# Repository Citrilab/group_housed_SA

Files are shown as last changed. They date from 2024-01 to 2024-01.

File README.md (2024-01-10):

# group_housed_SA
This repository includes appendix files for the paper: 
"An automated group-housed oral fentanyl self-administration method in mice" 
published in Psychopharmacology. 
It contains information regarding the assembly and use of the HOMECAGE (Home-cage Observation and Measurement for Experimental Control and Analysis in a Group-housed Environment).

3 folders are included:
* Assembly files - how to build a cage hardware, technical details, and 3D print files. 
* protocols – protocols for fixed ratio and progressive ratio self-administration group housed experiments in an automated cage, meant to be run by ‘Bpod’ hardware and software (https://sanworks.github.io/Bpod_Wiki/)
* Bpod helper – A GUI that helps the user to manage a group housed experiment using Bpod. including a user manual for this GUI.

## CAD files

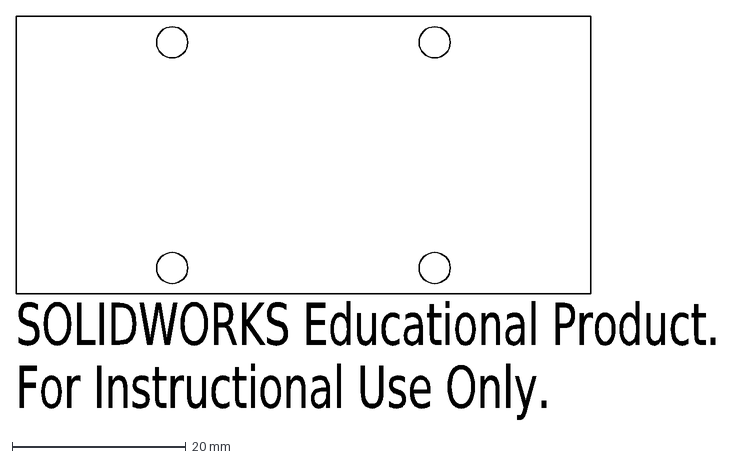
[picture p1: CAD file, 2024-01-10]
Assembly files/behavioral zone/Plexiglass top .DXF
SOLIDWORKS Educational Product.
For Instructional Use Only.

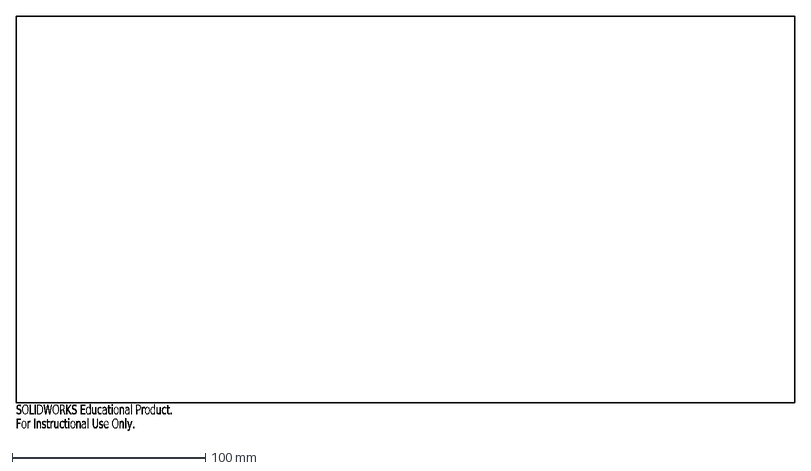
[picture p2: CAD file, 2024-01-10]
Assembly files/cage/Sides (2 parts).DXF
SOLIDWORKS Educational Product.
For Instructional Use Only.

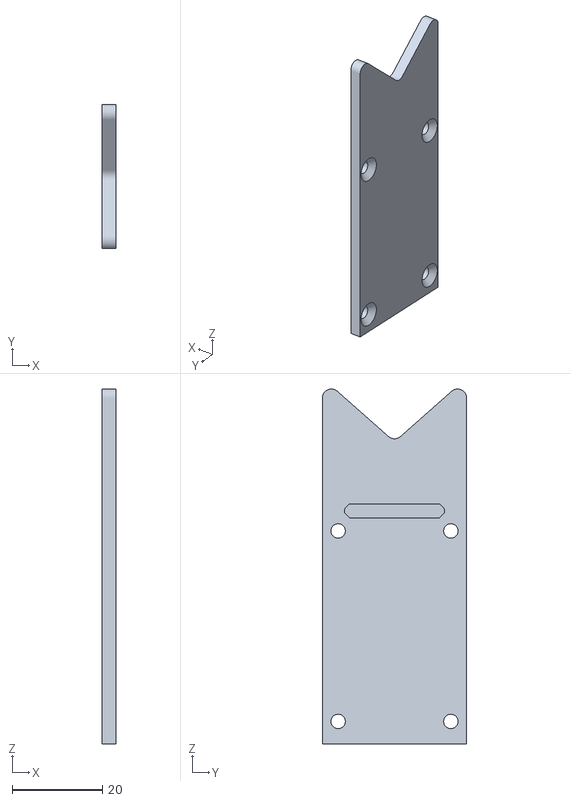
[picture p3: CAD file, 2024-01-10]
Assembly files/behavioral zone/side 1.STL
3.00 x 32.0 x 78.7

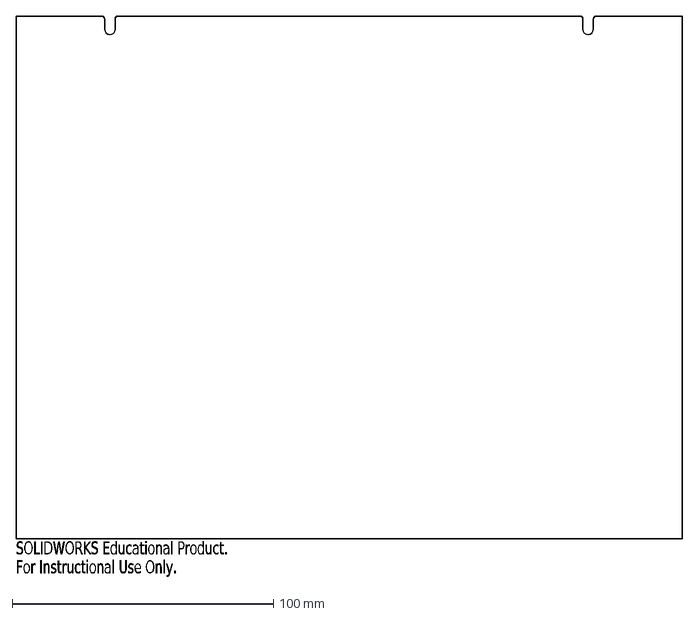
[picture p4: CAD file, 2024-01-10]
Assembly files/cage/Back.DXF
SOLIDWORKS Educational Product.
For Instructional Use Only.

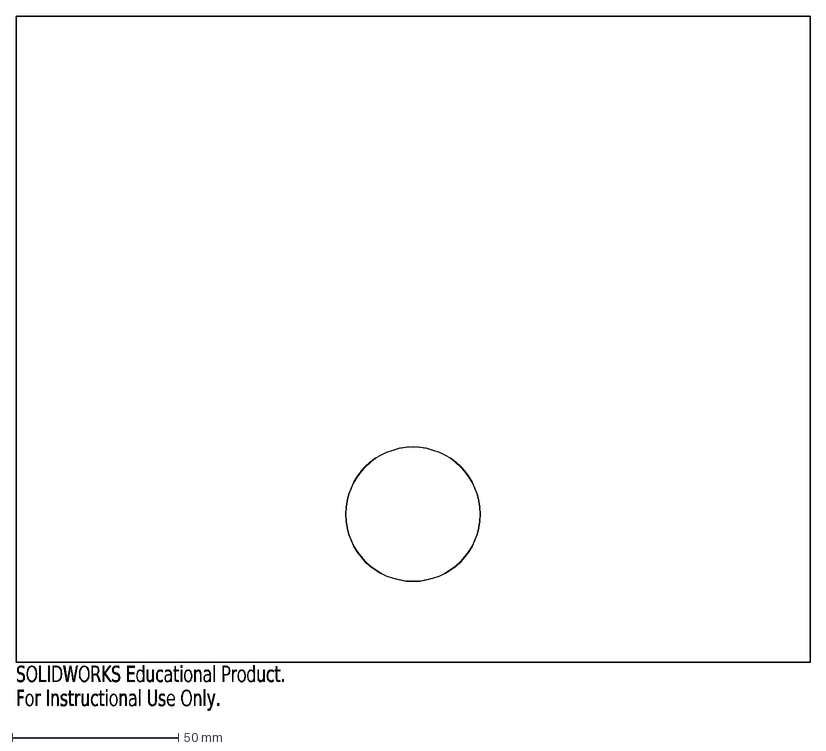
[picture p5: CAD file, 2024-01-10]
Assembly files/cage/Partition.DXF
SOLIDWORKS Educational Product.
For Instructional Use Only.

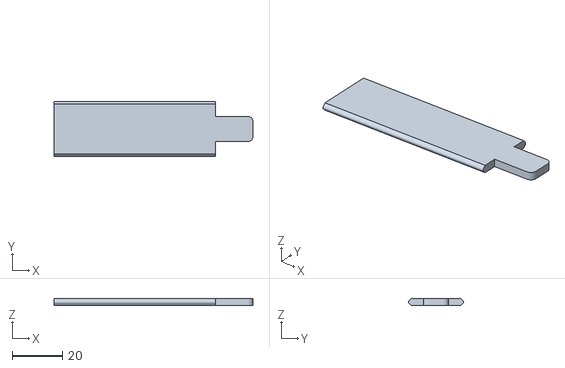
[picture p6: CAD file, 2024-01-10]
Assembly files/behavioral zone/floor.STL
79.3 x 21.9 x 2.70

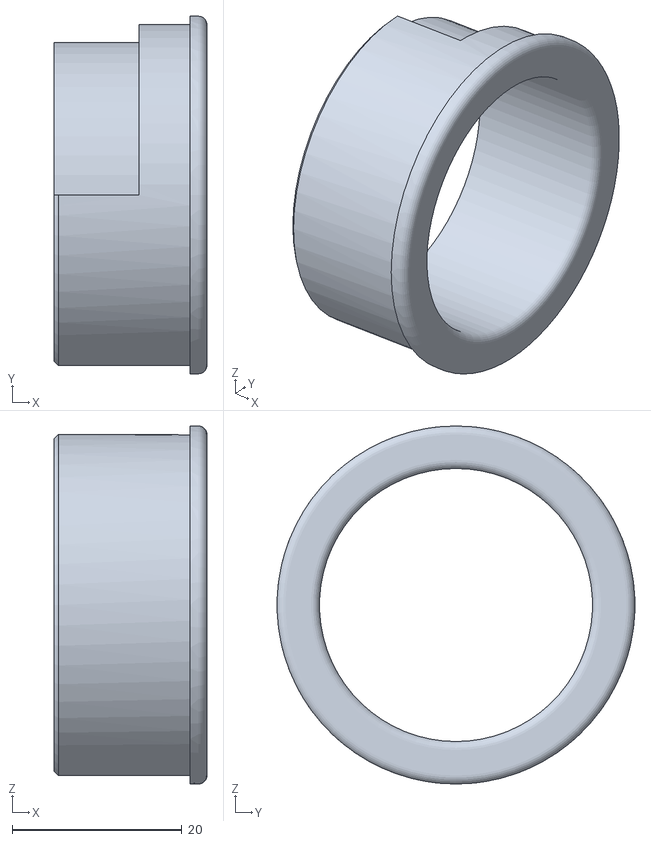
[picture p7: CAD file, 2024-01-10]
Assembly files/cage/Pipe holder.STL
18.0 x 42.1 x 42.1

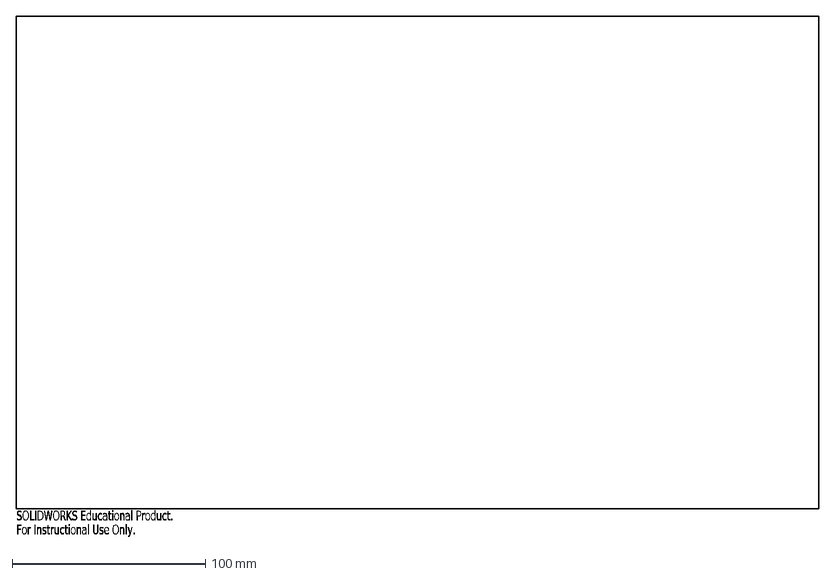
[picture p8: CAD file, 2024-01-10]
Assembly files/cage/Floor.DXF
SOLIDWORKS Educational Product.
For Instructional Use Only.

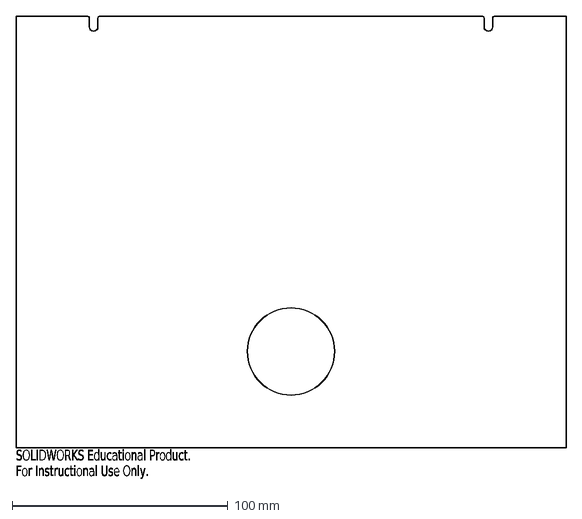
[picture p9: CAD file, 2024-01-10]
Assembly files/cage/Front.DXF
SOLIDWORKS Educational Product.
For Instructional Use Only.

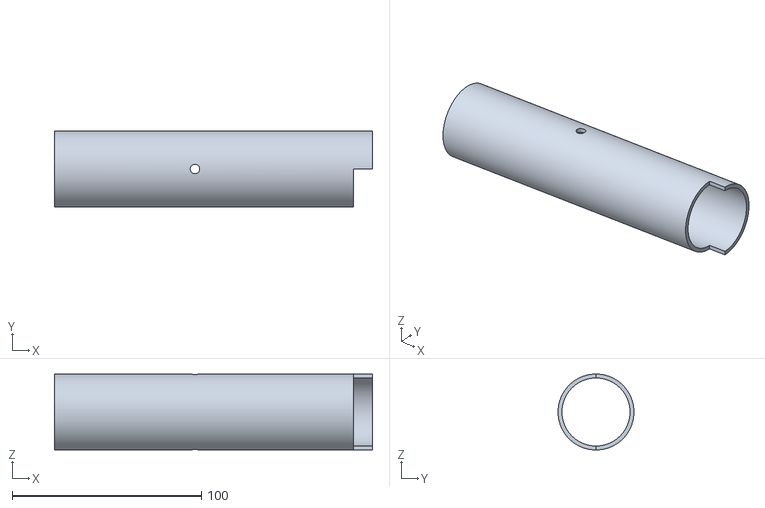
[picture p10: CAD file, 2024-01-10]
Assembly files/cage/Pipe for double port (Transparent).STL
168.0 x 40.1 x 40.1

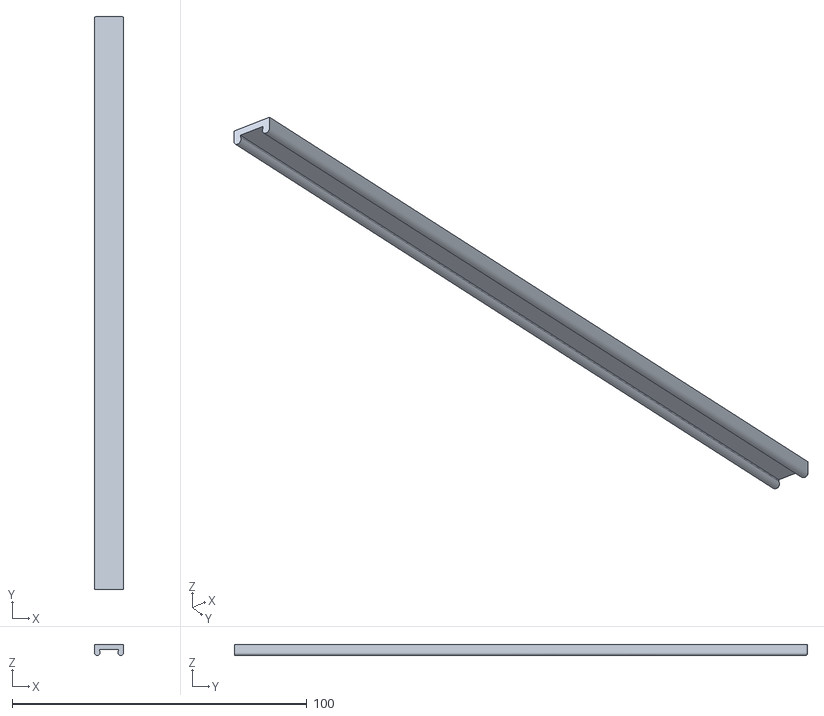
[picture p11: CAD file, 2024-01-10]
Assembly files/cage/Rails (2 parts).STL
10.0 x 194.3 x 3.70

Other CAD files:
Assembly files/behavioral zone/side 2.STL

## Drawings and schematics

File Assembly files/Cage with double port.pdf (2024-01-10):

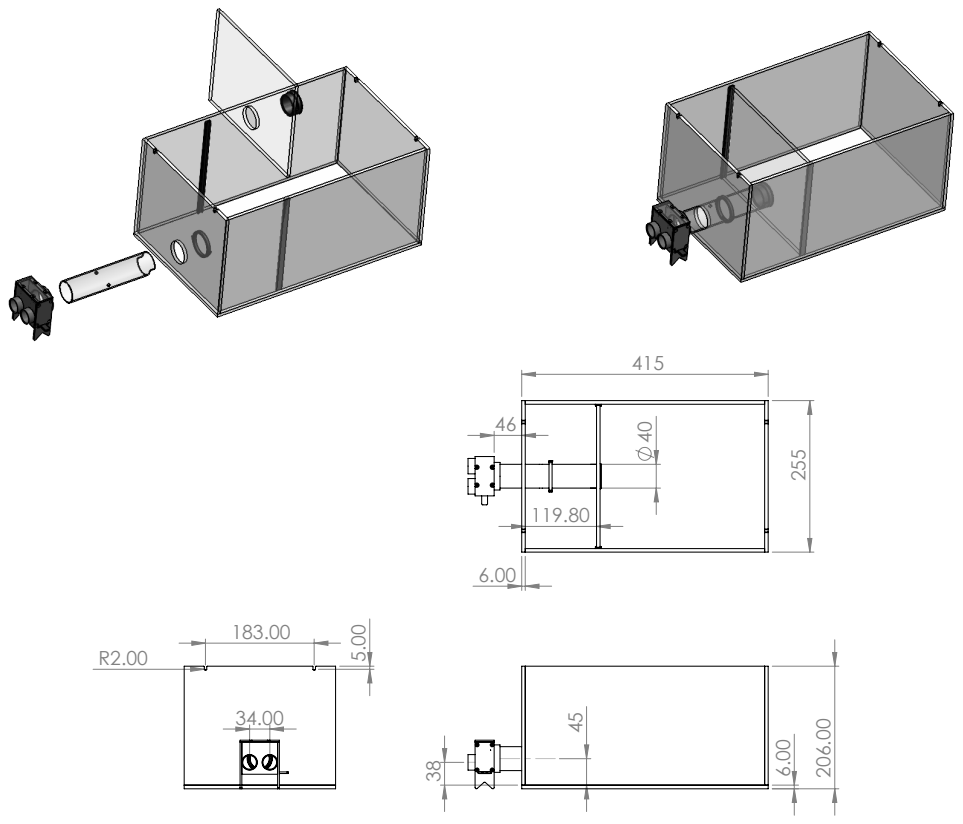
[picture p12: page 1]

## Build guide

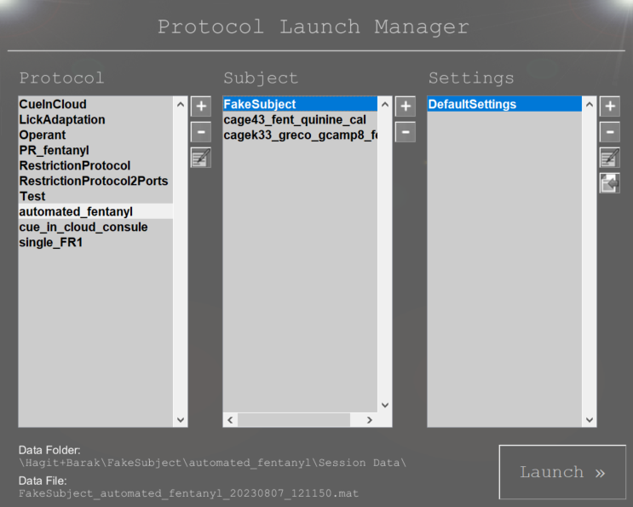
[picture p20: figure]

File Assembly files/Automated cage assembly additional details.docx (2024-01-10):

Automated cage assembly additional details:

1. For all of the 3D printings, I used black PLA fillament by Prusa, and printed with Prusa MK3S.
2. The cage was built with 6mm cast plexiglass sheets, milled with a simple CNC machine but could be cut by a laser machine.
3. The cage assembly could be done by Plexiglass glue or by screws (Holes for screws are not marked in the DXF files).
4. The main pipe is 40 mm OD and 36 mm ID plexiglass milled by a milling machine. An STL file is attached for 3D printing with a fine transparent material. Another option is to cut it with a 4 axis laser machine.
5. The rails for the partition could be glued with epoxy or R21 glue.

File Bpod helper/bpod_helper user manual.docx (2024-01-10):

Bpod helper GUI user manual:

*currently only windows OS supported

1. Download ‘bpod_helper.fig’, ‘bpod_helper.m’ and ‘Gui.m’ to your computer.
  - Make sure that the path to those files is in MATLAB’s path.
  - Make sure you have Instrument Control Toolbox installed
2. Change the following lines in ‘bpod_helper.m’ code to match the path to your data folders:
  - Line 61: path to the folder where you intend to save ‘animals’ files (i.e. a table with the RFID tags and the corresponding names of the mice in the cage).
  - Line 62: path to Bpod protocols (Bpod default is …. Documents\Bpod Local\Protocols)
  - Line 63: path to the folder where you intend to save experiment settings.
  - Line 73: the RFID code of a tester tag, change gui.data.TESTER_RFID

It is advised to dedicate an RFID tag for manual testing of the experiment. It is automatically added to every list of tags of mice currently participating in the experiment, is named ‘0’, and receives the default settings. Every faulty or unrecognized read will be treated as the tester and will appear in the data as related to the tester.

3. Identify how the RFID is recognized by your PC (i.e. what is its COM number):
  - Open windows device manager, expand the ‘Ports (COM&LTP) ’ tab.

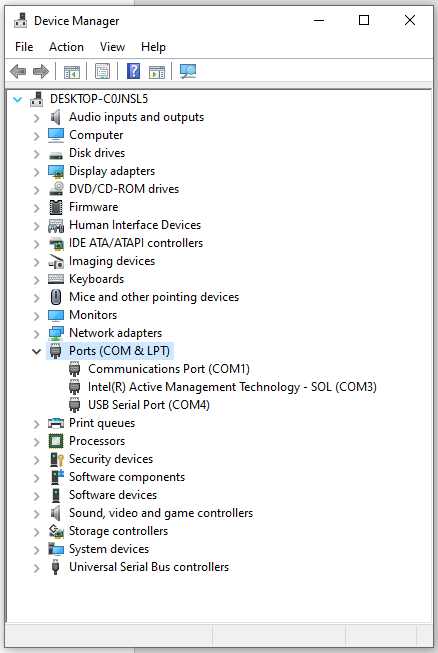
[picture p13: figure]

  - Look for a USB Serial Port. (To make sure you identified the one dedicated to your RFID reader, eject its cable and make sure the relevant COM is no longer presented). In this example, (where only an RFID is connected) the COM number of the RFID is ‘COM4’
4. Run ‘bpod_helper.m’, the GUI will open.
5. In order to start an experiment, first register the mice currently participating in the experiment to the automate cage, by choosing the ‘create new animals’ tab.

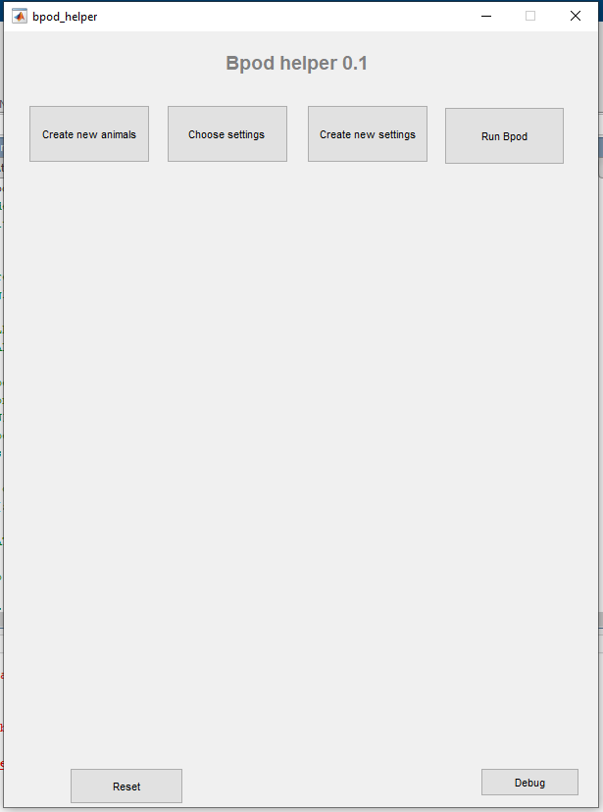
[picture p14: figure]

- If you are asked to provide the RFID COM number, enter it as identified in section 3.

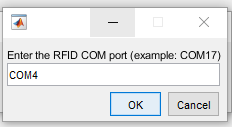
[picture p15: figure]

- Make sure the Bpod console is not open
- Scan the RFID of the mice one by one, hold the mouse and position the RFID close to its back where the tag is implanted. Once you are ready to scan a mouse hit the ‘Add new animal’ tab. Once a tag read was detected the GUI will ask you to approve the read. Make sure the RFID number is OK, and not a residual of previous reads that was buffered from the reader.

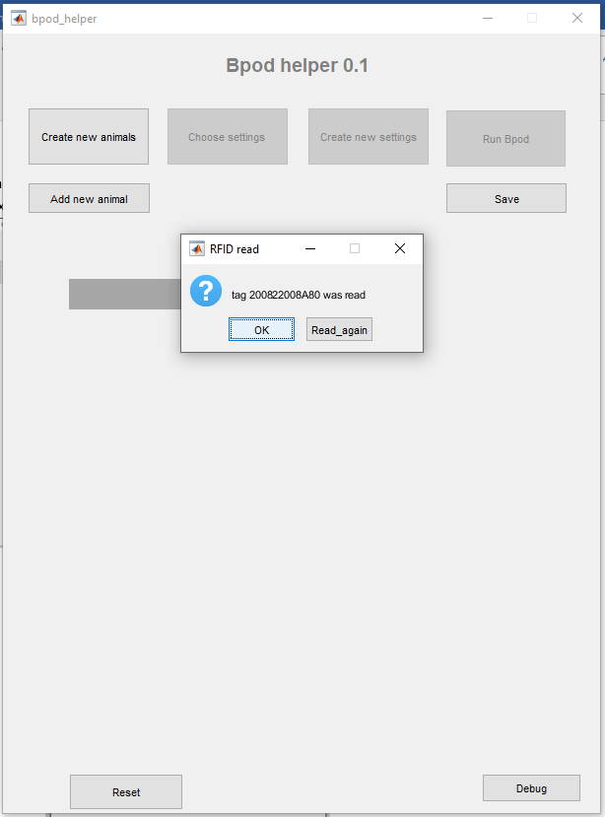
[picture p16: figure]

If the read is OK, name the current mouse, and continue to the next one. If not, or if it took too long to try and scan the mouse, read again.

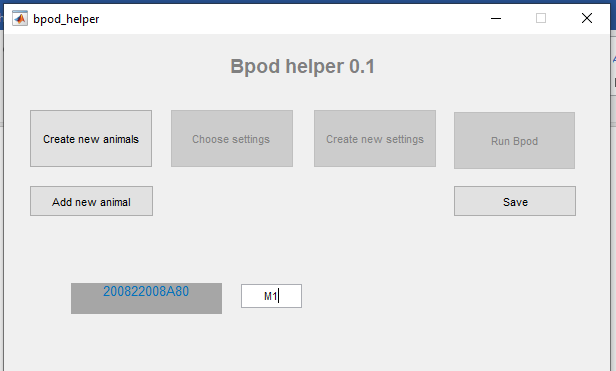
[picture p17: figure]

You will end up with a list of tags and the corresponding names.

- Save the ‘animals’ list by hitting the ‘save’ button. The default path for saving would be the one inserted in line 61 (section 2)
6. Create settings file for individual mice. For each protocol there are different parameters that could be changed. In our provided FR protocol, the ratio for rewards (the number of pokes), and the reward size (in ul) can be controlled.
- If you wish to design your own protocol and use the Bpod helper to control a group housed experiment, create a default settings structure and save it under the name ‘…/settings/template.mat’ in the protocol folder.
- If the Bpod helper was already open you can hit the ‘Reset’ button, and then hit the ‘create new settings’ tab.
- Choose protocol from the protocols list (folders in the path set in line 62, section 2), you will be provided the option to insert the settings of interest. Save the created settings by hitting the ‘save’ button
- There is an option to load existing settings file to examine and modify it.

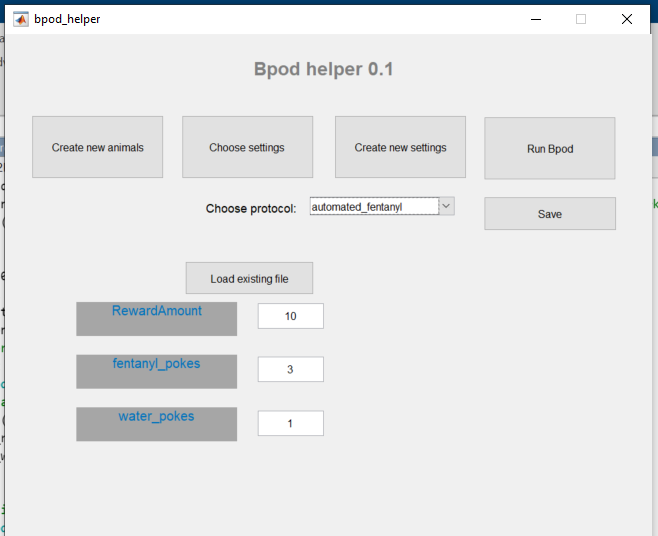
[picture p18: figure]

7. Choose settings for the individual animals. Choose protocol from the protocols list (same as in section 6), choose animals file (created in section 5).
  - For each mouse choose a settings file (created in section 6). Mice can share the same settings or have differential settings according to the experimental design. Save the settings under the folder where you intend to save the data from the experiment. (….animals_name/protocol_name/setings_file)
  - There is an option to load existing table of setting Assignment per mouse in the cage to examine and modify it.

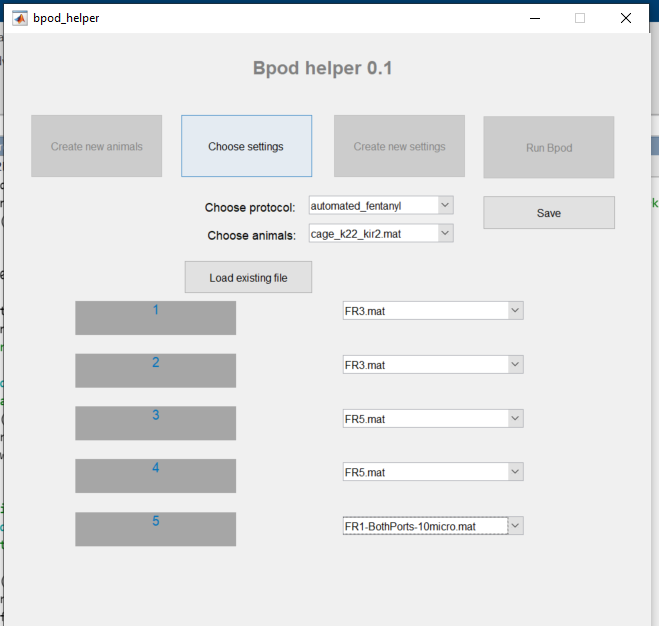
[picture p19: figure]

8. Now you can run the experiment from Bpod console. Choose your protocol, choose a subject name that corresponds to your cage name, and choose the table of settings per mouse as your settings file. If Bpod doesn’t recognize your settings table file, brows to import it from the saved location (the import button in Bpod console is marked in red in the screenshot below).
